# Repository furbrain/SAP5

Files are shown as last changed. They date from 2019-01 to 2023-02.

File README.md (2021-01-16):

# Shetland Attack Pony v5

The Shetland Attack Pony (SAP) now has an integrated laser range finder, and comes with a OLED display, optional bluetooth capability and a wide variety of beeping noises.

[Demo video on YouTube](http://www.youtube.com/watch?v=q_M8_QxNhjs)

## Get Started

**To turn on:**<br>
Press the button

**To turn off:**<br>
Press the button twice in quick succession

**Take a measurement**<br>
Press and hold the button

**To access the menu from the ready to measure screen**<br>
Shake the device

**Navigating menus:**<br>
Tilt the device briefly towards you - this will move on to the 
next menu item. Clicking the button will select that menu item

__DO NOT LOOK DIRECTLY INTO THE LASER BEAM:__ this can cause permanent
eye damage, although a brief exposure of less than a second is
unlikely to cause harm.

## Introduction

The SAP has three main operating modes: 

* [Ready to Measure](#Ready to Measure)
* [Data](#Data)
* [Menu](#Menu)

In many of these modes you will have top and bottom information rows.
Top left shows the time, and top right shows current battery. If you have a bluetooth module installed, you will see a bluetooth symbol, which will indicate whether the device is connected via bluetooth or not. 
The bottom row shows the current measurement style and units

## Ready to Measure

This is the first mode you will meet on starting the SAP. You will see a laser symbol, indicating the SAP is ready to take a reading. When taking a measurement, make sure the SAP is not near any sources of magnetic interference -  headlights, watches, metal anchors.

Press and hold the button to take a reading, keeping the laser dot lined up on your target. The SAP will make a single beep if the reading was successful, and will enter the [Data mode](#Data).

If the reading was unsuccessful you will hear an error noise and the display will briefly display the cause of the error, then return to Ready to Measure.

To directly access [Menu mode](#Menu), just shake the device.

## Data

This mode shows the data from the most recent measurement. If you have set the [display style](#Display style) to Compact then everything will be visible on a single screen. If not, you will need to scroll between the various readings. The default is to display compass reading in degreees, followed by clinometer reading, then distance in metres and finally extension (horizontal distance). You can choose different units of length and angle in [Settings -> Units](#Units), and you can also choose to just view offset in terms of Easting, Northing and Vertical in [Settings -> Style](#Style).
If you press the button on any of the data screens you will return to [Ready to Measure](#Ready to Measure).

There are a few additional options:

### Store
This allows you to store the data to the memory of the SAP and later retrieve it as a survex file using PonyTrainer. If you select this item, it will default to choosing the next leg (e.g) 1 -> 2 or 2->1. You can also select a splay leg with 1-> - or 2 -> -. If neither of these are suitable you can choose custom and specify which two stations this leg connects.

### Discard
Discards the data and return to [Ready to Measure](#Ready to Measure).

### Main Menu
Go to the [Menu](#Menu).

## Menu
### Settings

#### Units (default: metric)
Choose between *metric* (metres) and *imperial* (decimal feet).

#### Style
##### Polar (default)
Directional readings are shown in degrees.

##### Grad
Directional readings are shown in grads. There are 400 grads in a circle.

##### Cartesian
Instead of compass and clino readings, the northing, easting, and vertical distances are
shown. This can aid sketching when used with graph paper. It is also the format
that data is stored internally.

#### Display
##### Compact
When you have taken a reading, show all the data on a single screen
##### Large
When you have taken a readingm, show each data item on it's own screen.

#### Timeout (default 30s)
Select the length of time after which the device turns itself off without any input.

#### Set Date
Sets the current date. For each digit in the date, flip the device away or towards
you to set the correct date. Move on to the next digit by pressing the button.

#### Set Time
Sets the current time. For each digit in the time, flip the device away or towards you to set the correct date. Move on to the next digit by pressing the button.

### Calibrate
This option allows you to calibrate the various sensors within the device. With normal operation, you should only need to use the Calibrate Sensors item - you should do this every few months, or whenever you change general location so that the strength and dip of the magnetic field has changed

#### Sensors
At each stage the screen will give instructions.

1. Place the device flat against an __inclined__ surface and wait for the beep. 
After each beep rotate through 90 degrees - it will take four readings in total.
The positions do not have to be exact, but the device must be still for the half-second before each beep.

2. Place the device flat on a level(ish) surface. After the first beep turn it so the laser is pointing straight up.
After second beep place it with the display facing down. After the third beep place it so the laser is pointing downwards
The positions do not have to be exact, but the device must be still for the half-second before each beep.

3. Hold the laser against a solid point with the laser on a fixed point at least 2 metres away. After each beep
rotate by about 45 degrees, while keeping the laser pointing at the same place. There will be eight
readings in total. It is important that you keep the laser pointing at the same point for each reading.

4. Repeat step 3 using different points, ideally about 90 degrees from the previous set.

The screen will then display some accuracy statistics - ideally the final number should be 1.00 or less.
If the accuracy is good enough, then the calibration will be saved to the devices memory.

#### Laser

This allows you to calibrate the distance returned by the laser. You should only need to do
this if you add anything to the rear of the device or if you want to measure from the front
of the device.

1. Before selecting this option measure a distance of exactly 1m to a flat surface.
2. After selecting this option, place the device so the point you want to measure from is exactly
1m from the flat surface.
3. The device will make 10 beeps and display the new offset for the laser and the error number - this should
be 0.002 or less.

#### Axes

This allows the device to work out which sensors are pointing in which direction. You should not
need to do this unless you have an experimental device.

### Measure
Return to [Ready to Measure](#Ready to Measure)

### Visualise
If you have been storing your recorded legs, this allows you to see what you have recorded so far.
You will see all the legs recorded in the curent survey, move the device to get a different perspective.
Hold the device horizontal and you will see it in plan view. Hold it vertically and you will get an elevation.

This feature is still in development.

### Info
This menu item shows several screens with basic information. It can allow some troubleshooting. Several of 
these refer to the various axes of the device. The y-axis is in the direction of the laser beam. The z-axis goes
up through the top of the device, and the x-axis is at right-angles to both of these.

#### Raw
Show the raw sensor readings. Magnetic readings are in μT, gravitational readings are in g (1g = 9.81ms<sup>-2</sup>).

#### Calibrated
Show the calibrated readings, the top reading is the total field strength (in μT for magnetism, g for gravity).

#### Bearings
Show the current compass and clin readings for the device. Also displays the device name

There are also screens that show the exact battery voltage and firmware/hardware versions

### Off
Turns the device off

## Battery Life
The main draw on the battery is the laser pointer. From a full charge
the device will remain on continuously for about 2½ hours, assuming 15 seconds to read out the compass and clino, 3s
of laser usage to identify the target station and 3s of reading. You should get approx 300 sets of readings,
but your actual results will vary depending on how long you keep the laser on for and
the ambient temperature.

When the battery is getting low you will first get a warning when the device turns on. When the battery is
critically low, the device will not turn on and just make an "error" noise.

## Known Issues

* Visualisation mode is not thoroughly tested.

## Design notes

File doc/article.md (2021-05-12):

Non-linear calibration of a digital compass and accelerometer

#Introduction

The Shetland Attack Pony (SAP) is a cave surveying tool, which has undergone several iterations in its lifetime **FOOTNOTE**. The original version was the first electronic compass/clinometer developed for caving  In its current form it consists of a 32bit CPU (PIC32MM0256GPM028 **FOOTNOTE**), a lithium-ion battery, an OLED display, a laser range finder, an accelerometer (LSM6DS3 by ST **FOOTNOTE**) and a magnetometer (BM1422AGMV by Rohm **FOOTNOTE**). This is an open source project - all the code and hardware designs can be found on Github.

#Principle of Operation

##Laser rangefinder
The laser rangefinder uses a simple time-of-flight algorithm - it sends out pulses of laser light and records the time taken for those pulses to be received back. These are typically accurate to +/- 1mm,

##Magnetometer
The BM1422AGMV uses 3 orthogonal magneto impedance sensors. These consist of a thin film of soft ferromagnetic materials with the special property that their impedance to high frequency alternating current is highly sensitive to any external magnetic fields. The associated IC therefore generates a high frequency alternating current and measures the impedance to determine the magnetic field. This specific sensor is accurate to +/-0.042 uT (Earth's horizontal magnetic field component is typically up to 30 uT, depending on location)

##Accelerometer
The LSM6DS3 use a micro-electro-mechanical system (MEMS) to measure acceleration. This consists of a small mass of silicon on a cantilever between two plates. Under acceleration, the mass moves towards one of the plates, altering the capacitance between the mass and the plate. The LSM6DS3 consists of 3 of these assemblies in an orthogonal pattern. It is accurate to 90 ug (where one g is 9.81 ms^-2)

##Priniciple of determining orientation

###Coordinate system
We shall imagine the SAP initially to be lying flat on a plane with the display upwards. The y coordinate extends in the positive direction parallel to the laser. The z-coordinate extends in a positive direction up through the display. The x-coordinate extends in a positive direction to the left when looking down at the display with the laser pointing away from you 

###Determining orientation
We can use the Magnetometer to determine a vector for gravity g and magnetism m, we can therefore calculate vectors for East and North using the cross-product. 

E = G^ X M^
N = E^ X G^ 

O = (E^ N^ G^)

The matrix O then forms an orthogonal basis and we can use this to translate the y-vector (i.e. the direction of the laser beam) (0,1,0) into real world coordinates y'

y' = yO^T
azimuth = atan2(Y'_1, Y'_0)
inclination = atan2(|(y'_0,y'_1)|, y'_2)

#Traditional calibration

The above calculations of course assume that we have perfect sensors, each exactly aligned, and that there is no magnetic interference from any other components. Unfortunately, none of these assumptions are true. We can divide the potential sources of error into errors intrinsic to the sensors and extrinsic errors

##Intrinsic Errors
Each sensor has an offset β_sensor and a scale factor A_sensor, and also a degree of non-linearity. Non-linearity is the degree to which the sensor reading departs from the straight line, we shall denote it here as psi(x). 

x_sensor = A_sensor x_raw + β_sensor + psi(x_raw)

##Extrinsic Errors
The incident magnetic field on the sensor can be affected by both hard iron β_sensor (which is a simple offset) and soft iron effects A_soft iron(which can be a shear and scale error) within the device.Each sensor can also be rotated with respect both to the ideal orthogonal position, so we also have a 3x3 rotation matrix R for each set of sensors

x = R . A_soft_iron (x_sensor + β_hard_iron)

For the time being, we will ignore the non-linearity term, and we can simplify all this to 

x = A(x_raw + β) 

where A is a 3x3 matrix and β is a 3-vector

##Basic calibration process
We can make a first estimation at A and β by noting that both the gravitational and magnetic fields in any single location should be constant (at least over the time taken to calibrate the device). We take a series of 24 readings, of which eight are distributed in multiple directions and orientations. The other 16 are two sets of eight readings all taken from the same origin to two destination points, with the device held in varying degrees of roll along the y axis. This gives us a cloud of points which are distributed on the surface of an ellipsoid. We can use the process described 

#Issues with non-linearity

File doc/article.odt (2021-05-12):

Non-linear calibration of a digital compass and accelerometer

# Introduction

The Shetland Attack Pony (SAP) is a cave surveying tool, which has undergone several iterations in its lifetime[1][2].The original version was the first electronic compass/clinometer developed for caving In its current form it consists of a 32bit CPU (PIC32MM0256GPM028 by Microchip[3]), a lithium-ion battery, an OLED display, a laser range finder, an accelerometer (LSM6DS3 by ST[4]) and a magnetometer (BM1422AGMV by Rohm[5]). This is an open source project - all the code and hardware designs can be found on Github[6].

# Principle of Operation

## Laser rangefinder

The laser rangefinder uses a simple time-of-flight algorithm - it sends out pulses of laser light and records the time taken for those pulses to be received back. These are typically accurate to +/- 1mm.

## Magnetometer

The BM1422AGMV uses 3 orthogonal magneto-impedance sensors. These consist of a thin film of soft ferromagnetic materials with the special property that their impedance to high frequency alternating current is highly sensitive to any external magnetic fields. The associated IC therefore generates a high frequency alternating current and measures the impedance to determine the magnetic field. This specific sensor is accurate to +/-0.042 μT (Earth's horizontal magnetic field component is typically up to 30 μT, depending on location)

## Accelerometer

The LSM6DS3 use a micro-electro-mechanical system (MEMS) to measure acceleration. This consists of a small mass of silicon on a cantilever between two plates. Under acceleration, the mass moves towards one of the plates, altering the capacitance between the mass and the plate. The LSM6DS3 consists of 3 of these assemblies in an orthogonal pattern. It is accurate to +/-90 μg (where one g is 9.81 ms⁻²)

## Determining orientation

We shall imagine the SAP initially to be lying flat on a plane with the display upwards. The y-coordinate extends in the positive direction parallel to the laser. The z-coordinate extends in a positive direction up through the display. The x-coordinate extends in a positive direction to the left when looking down at the display with the laser pointing away from you

We can use the magnetometer and accelerometer to determine a vector for gravity g and magnetic field m. From these we can calculate vectors for East and North using the cross-product.

bold e = bold hat g times bold hat m newline
bold n = bold hat e times bold hat g newline
O = ( bold hat e bold hat n bold hat g )

The orientation matrix O then forms an orthogonal basis and we can use this to translate the y-vector (i.e. the direction of the laser beam (0,1,0) ) into real world coordinates y

bold y = O left (stack { 0 # 1 # 0 } right ) newline
azimuth = func atan2(y_1, y_0) newline
inclination = func atan2( sqrt{y_1^2 + y_0^2}, y_2 )

# Traditional calibration

The above calculations of course assume that we have perfect sensors, each exactly aligned, and that there is no magnetic interference from any other components. Unfortunately, none of these assumptions are true. We can divide the potential sources of error into errors intrinsic to the sensors and extrinsic errors

## Intrinsic Errors

Each sensor has an offset βsensor and a scale factor Asensor, and also a degree of non-linearity. Non-linearity is the degree to which the sensor reading departs from the straight line, we shall denote it here as an arbitrary, unknown function ψ(x), where x is the sensor reading.

bold x_sensor = A_sensor bold x_raw + bold β_sensor + %psi(bold x_raw)

## Extrinsic Errors

The incident magnetic field on the sensor can be affected by both hard iron βsensor (which is a simple offset) and soft iron effects Asoft iron(which can be a shear and scale transformation) within the device. Each sensor can also be rotated with respect both to the ideal orthogonal position, and also with respect to the device, so we also have a 3x3 rotation matrix R for each set of sensors.

bold x = R A_{soft iron} (bold x_sensor + bold β_{hard iron})

For the time being, we will ignore the non-linearity term, and we can simplify all this to

bold x = A(bold x_raw + bold β)

where A is a 3x3 matrix and β is a 3-vector

## Basic calibration process

We can make a first estimation at A and β by noting that both the gravitational and magnetic fields in any single location should be constant (at least over the time taken to calibrate the device). We take a series of 24 readings, of which eight are distributed in multiple directions and orientations. The other 16 are two sets of eight readings all taken from the same origin to two destination points, with the device held in varying degrees of roll along the y axis. This gives us a cloud of points which are distributed on the surface of an ellipsoid. We can use the process described in Vitali[7] to calculate the closest values for A and β. This method is rather involved but essentially calculates the matrix and offset required that would translate all of the stored data points onto the surface of a unit sphere located at the origin, and minimises the average distance of any translated point from that surface. The error of this process can be estimated as below where N is the number of readings.

h_magnitude = sqrt{ sum from{i=0} to{N} {(abs {bold x_i} - 1)^2 over N} }

## Correcting for rotation

Once this process is complete, we still have the possibility of error due to misalignment between our sensors and the laser pointer. Essentially we need to find the vector v in sensor coordinates that corresponds to the direction of the laser pointer. Consider the two sets of eight readings taken during calibration – for each set the angle between the laser pointer and the magnetic/gravitational fields will be constant. They will therefore be located on a plane, which is normal to v.

a X + b Y + c Z = 1 newline

D left ( stack{ a # b # c} right )= left ( stack{1 # dotsvert # 1} right ) newline

bold v = left ( stack{ a # b # c} right )

We can use the equation for a plane to construct an equation where D is a 3x8 matrix consisting of the sensor readings from the particular set of readings. Solving this with a least squares technique gives us a, b, and c which can be used to construct v. Once v is determined, it is trivial to construct a rotation matrix that can be applied to A to give us sensor readings in device coordinates.

We can also use these sets of readings to develop another measure of accuracy – essentially how similar the laser pointer vectors are in real world coordinates:

h_orientation = sum from {i=0} to N {abs{bold y_i - bold bar y} over N}

yi is the ith reading of a set in real world coordinates and bold bar y is the average of all of those readings.

# Issues with non-linearity

The previous calibration process worked on the principle that the output of the sensors varies linearly with the incident magnetic or gravitational field. This is not always true, and the output of the BM1422AGMV in particular can have non-linearity of up to 2.8%. Figure 1 shows the consequences of a 0.01 error (where 1 is the maximum reading when the sensor is aligned with the magnetic field). As we can see the error in magnitude is greatest at larger sensor values, whereas the error in the azimuth (which is what we are interested in as cave surveyors) is greatest around the zero point. As the traditional calibration algorithm seeks to minimize errors in magnitude

To progress we need to find a way to determine the unknown function ψ(x). One common way to approximate an unknown function is to use polynomial fitting e.g:

%psi( bold x ) = sum from i=0 to P p_i x^i

Where pi is the ith of P polynomial coefficients. Usually somewhere between 2 and 10 coefficients are sufficient to approximate any arbitrary continuous function. Unfortunately polynomial equations behave badly outside of the fitted range, which may cause problems if the device is moved to other locations with a stronger magnetic field. Instead, we can use a radial basis function as below.

%psi(bold x) = sum from {i=0} to P %phi(p_i, a_i, bold x) newline

%phi(p, a, bold x) = p func e^{-((bold x' - a) P/2 )^{2}} newline

a_i = left lbrace matrix { 0 # func if P=1 ## {2i} over {P-1} - 1# func if P > 1} right rbrace

This creates a set of P gaussian curves that can be added together to form an arbitrary function, but which rapidly tail off outside the interval (-1,1). x’ is the raw sensor value, scaled and offset to fit in the range (-1,1) - scale and offset factors can easily be calculated from A and β. Figure 2 shows a arbitrary function constructed from these radial basis functions. As you can see these functions tend towards zero outside of their fitted range.

We can now use a minimisation algorithm to find the ideal values for p that minimises h (note that we still need to include hmagnitude as otherwise the minimisation algorithm can find extreme values)

bold p = func argmin_{bold p} h newline
h = h_orientation + h_magnitude

In principle we could then repeat the ellipsoid fitting algorithm; however in practice this does not produce any substantial gains in accuracy.

# Overfitting

One risk of approximating arbitrary functions is that of overfitting – where the generated function is determined more by noise in the data than by the underlying structure. As we increase the number of parameters for We can assess for this using a “leave-one-out” technique – essentially running the whole calibration process excluding the first data point and seeing how well that data point is placed using the calibrated constants, and then repeating this over all data points. This can be done using different number of parameters, and we can generally find a “sweet spot” where we have enough parameters to model the non-linearity, but not enough to fall prone to overfitting. Figure 3 shows several data points, which shows some data points from the cosine function with some added noise, with several polynomial approximations shown. The red line is underfitted with only 3 parameters, and misses the peak of the curve and also the tails on either side. The blue line is overfitted, and you can see it responding to noise in the data points, and also rapidly becomes unstable outside of the fitted range. The green line is “just right”and models the general shape of the data without getting too distorted by noise.

# Results

Nine SAPs were constructed and calibration data was obtained as described in the basic calibration process. The calibration algorithm described was then applied with between 0 and 9 parameters for the non-linear correction (P). P=0 is equivalent to just using the “traditional” calibration method. The results are shown in Figure 4, and show that the majority of the benefit is achieved with 3 to 5 parameters, and then only gradual improvement thereafter with more parameters.

The same procedure was also performed using a leave-one-out strategy to determine if there is any overfitting. The results are shown in figure 5 – they demonstrate good improvement in accuracy with up to 5 non-linear parameters. Using more than 5 parameters impaired performance due to overfitting, with severe problems when 8 or more parameters are used.

# Conclusions

This paper has demonstrated that non-linear effects in magnetometers can cause significant errors for electronic compasses that cannot be compensated with traditional calibration mechanisms. Where devices have a pointer, these errors can be minimised with the use of the technique demonstrated.

However, this technique can only correct for non-linearity in the x and z axes, as the y-axis sensor reading will not change substantially during rotation around the y-axis. It should be possible to use the flat bottom of a survey device as a way to rotate the device accurately around the z-axis, and this may provide a way to obtain a y-axis non-linear calibration– this is yet to be explored.

# References

[1] P. Underwood, ‘A Combined Electronic Compass and Clinometer’, Cave Radio Electron. Group J., no. 66, pp. 12–14, Mar. 2007.

[2] P. Underwood, ‘Calibrating the Electronic Compass/Clinometer’, Cave Radio Electron. Group J., no. 69, pp. 10–13, Dec. 2007.

[3] Microchip Technology Inc., ‘PIC32MM0256GPM028 - 32-bit PIC Microcontrollers’. https://www.microchip.com/wwwproducts/en/PIC32MM0256GPM028 (accessed May 11, 2021).

[4] STMicroelectornics, ‘LSM6DS3 - iNEMO 6DoF inertial measurement unit (IMU), for consumer electronics - STMicroelectronics’. https://www.st.com/en/mems-and-sensors/lsm6ds3.html (accessed May 11, 2021).

[5] Rohm, ‘BM1422AGMV - 3-Axis Digital Magnetometer IC | ROHM Semiconductor - ROHM Co., Ltd.’ https://www.rohm.com/products/sensors-mems/geomagnetic-sensor-ics/bm1422agmv-product (accessed May 11, 2021).

[6] P. Underwood, SAP5 Github Repository. 2021. Accessed: May 11, 2021. [Online]. Available: https://github.com/furbrain/SAP5

[7] A. Vitali, ‘Ellipsoid or sphere fitting for sensor calibration’. STMicroelectronics. Accessed: Apr. 17, 2021. [Online]. Available: https://www.st.com/resource/en/design_tip/dm00286302-ellipsoid-or-sphere-fitting-for-sensor-calibration-stmicroelectronics.pdf

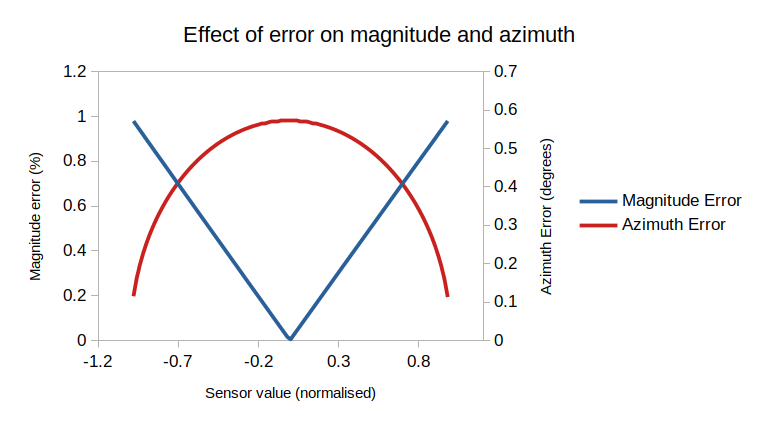
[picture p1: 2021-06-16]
doc/images/mag_azi_error.png

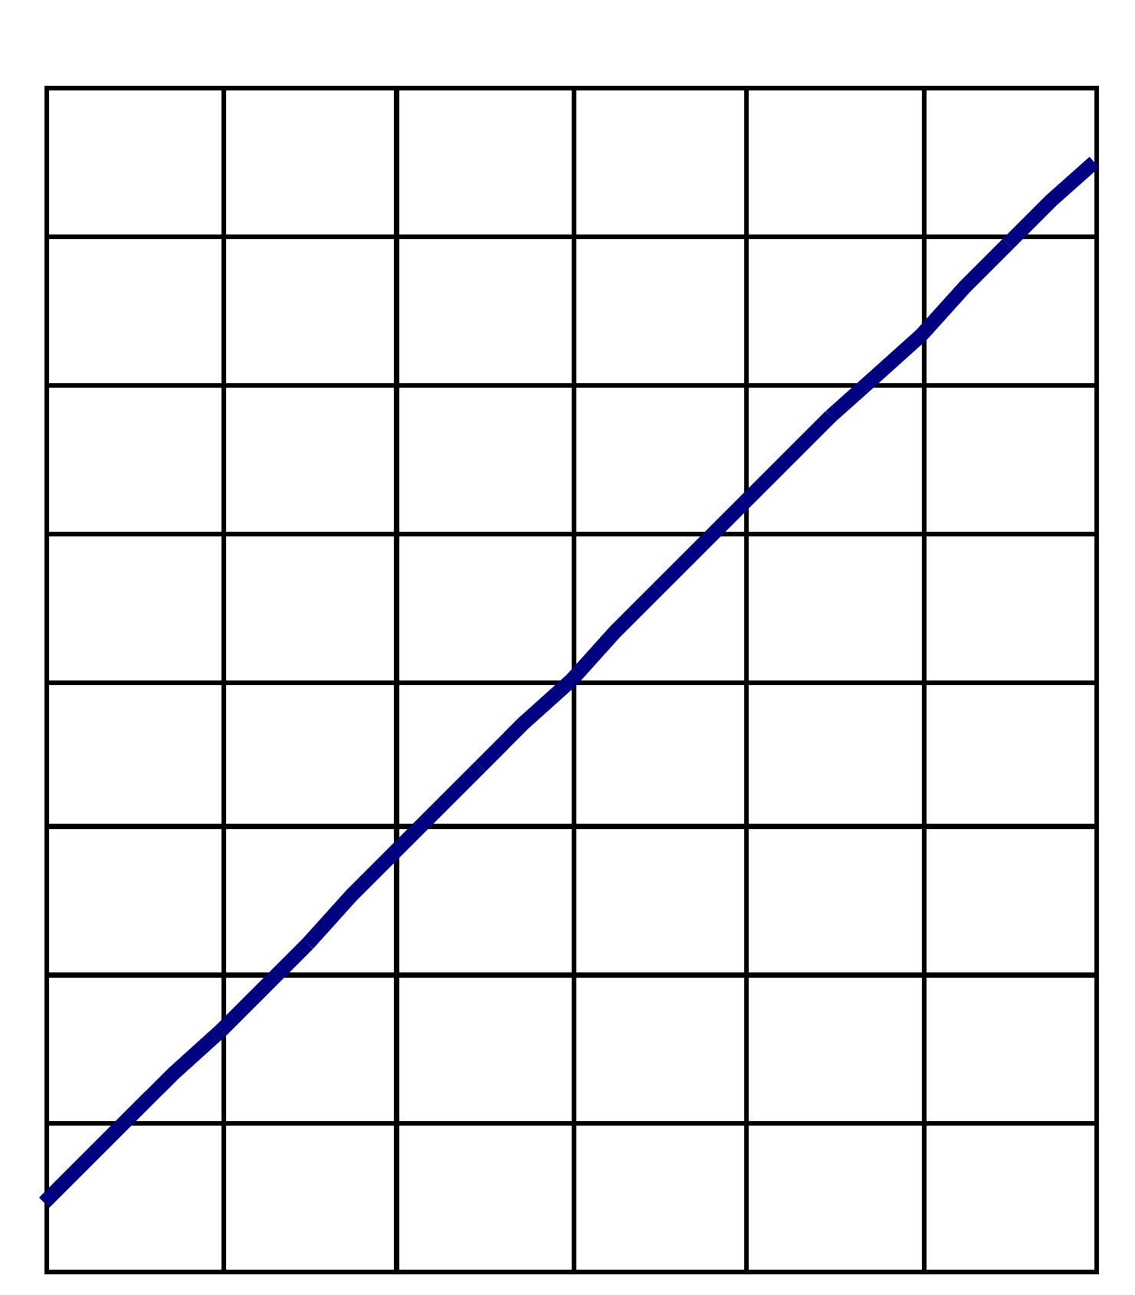
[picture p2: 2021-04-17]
chips/BM1422/graph.png

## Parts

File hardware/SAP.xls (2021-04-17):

Designator | MPN/Seeed SKU | Qty | Link
B1 | 320110026 | 1 | https://statics3.seeedstudio.com/images/opl/datasheet/3410050P1.pdf
C1, C2, C4, C21, C23, C26, C27 | 302010024 | 7 | https://statics3.seeedstudio.com/images/opl/datasheet/302010024.pdf
C3, C22 | 302010103 | 2 | https://statics3.seeedstudio.com/images/opl/datasheet/302010103.pdf
C11, C12, C14, C15, C19, C20 | 302010146 | 6 | https://statics3.seeedstudio.com/images/opl/datasheet/302010146.pdf
C24, C25 | 302010003 | 2
J4 | UJ2-MIBH-4-SMT-TR-67 | 1 | https://www.digikey.com.cn/product-detail/zh/cui-inc-/UJ2-MIBH-4-SMT-TR-67/102-4970-1-ND/9564435
R1, R10, R12 | 301010004 | 3 | https://statics3.seeedstudio.com/images/opl/datasheet/301010004.pdf
R2, R11 | 301010006 | 2 | https://statics3.seeedstudio.com/images/opl/datasheet/301010006.pdf
R3, R4, R5 | 301010009 | 3 | https://statics3.seeedstudio.com/images/opl/datasheet/301010009.pdf
R7 | 301010466 | 1 | https://statics3.seeedstudio.com/images/opl/datasheet/301010466.pdf
R8, R9 | 301010039 | 2 | https://statics3.seeedstudio.com/images/opl/datasheet/301010039.pdf
U1. | PIC32MM0256GPM028-I/SS | 1 | https://www.digikey.com.cn/product-detail/zh/microchip-technology/PIC32MM0256GPM028-I-SS/PIC32MM0256GPM028-I-SS-ND/7354783
U6. | XC6215B302MR-G | 1 | http://www.mouser.cn/ProductDetail/Torex-Semiconductor/XC6215B302MR-G
U8. | MC78LC30NTRG | 1 | https://www.digikey.com.cn/product-detail/zh/on-semiconductor/MC78LC30NTRG/MC78LC30NTRGOSCT-ND/1967131
U9. | MAX1555EZK+T | 1 | https://www.digikey.com.cn/product-detail/zh/maxim-integrated/MAX1555EZK-T/MAX1555EZK-TCT-ND/2699449
U10. | OV-7604-C7-32.768kHz-20PPM-TA-QC | 1 | https://www.mouser.cn/ProductDetail/Micro-Crystal/OV-7604-C7-32768kHz-20PPM-TA-QC
U11 | BM1422AGMV-ZE2 | 1
U12 | LSM6DS3TR | 1

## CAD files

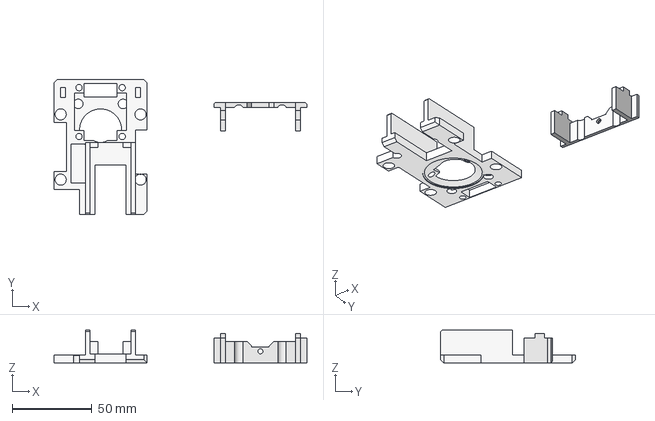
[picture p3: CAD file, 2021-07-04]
enclosures/frame.FCStd
158.5 x 84.4 x 20.5 mm
Base
Cage

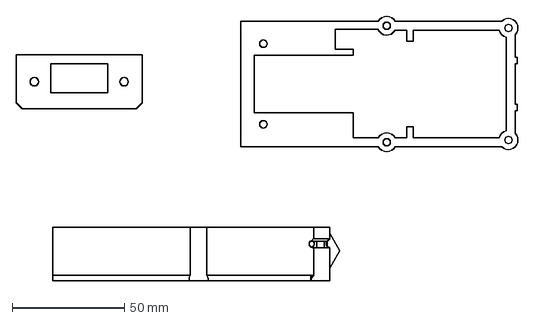
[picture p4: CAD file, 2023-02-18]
enclosures/v2/gaskets.dxf
223.9 x 118.0 mm

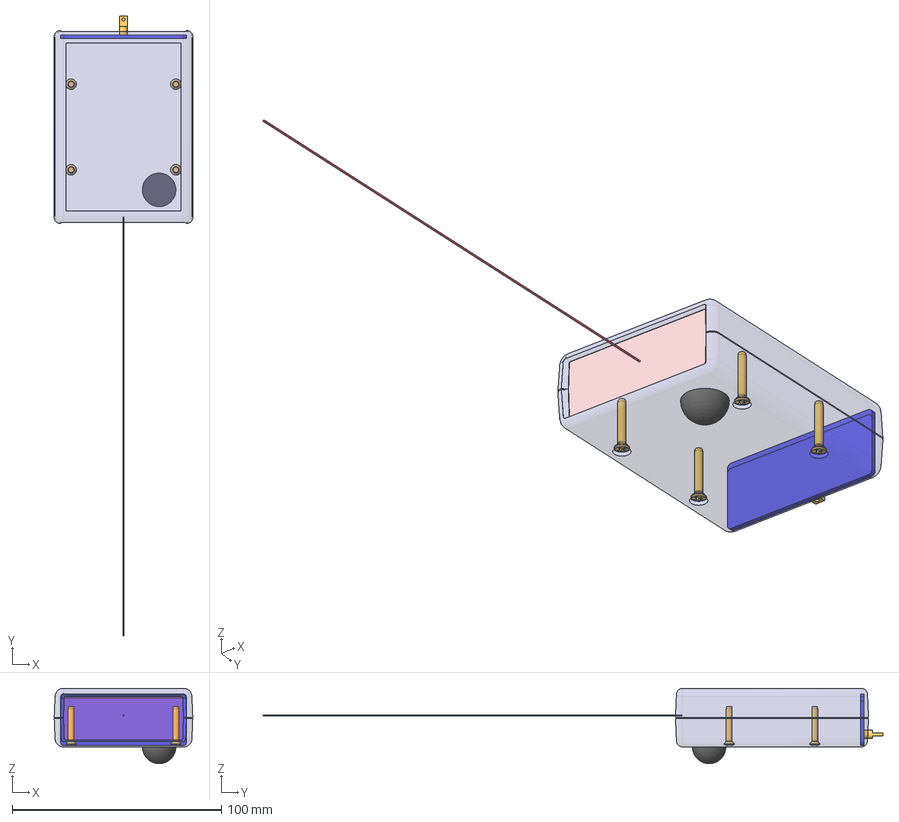
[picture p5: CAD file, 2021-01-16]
enclosures/model.FCStd
66.2 x 296.0 x 36.0 mm
_593L
_593L001
_593L002
_593L003
_593L007
_593L008
_593L009
_593L010

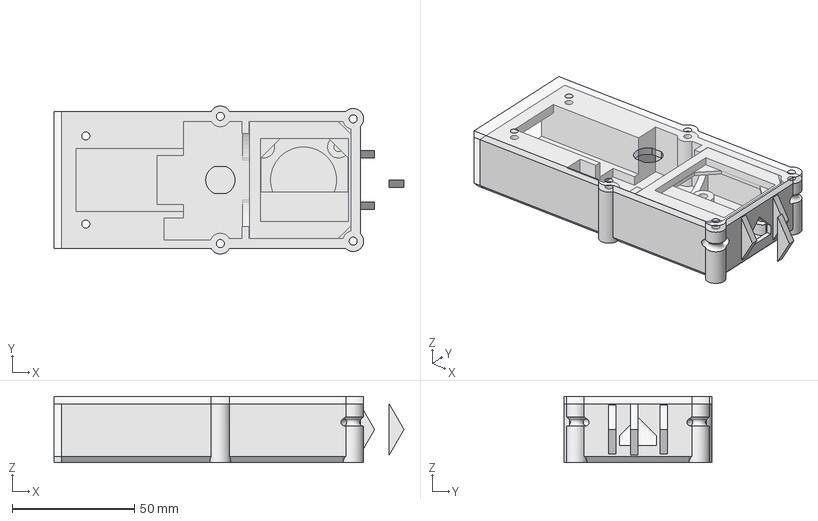
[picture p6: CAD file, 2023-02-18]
enclosures/v2/model.FCStd
143.1 x 60.5 x 27.0 mm
Main Body
Front Plate
Top Plate
LCD Holder
Noddle

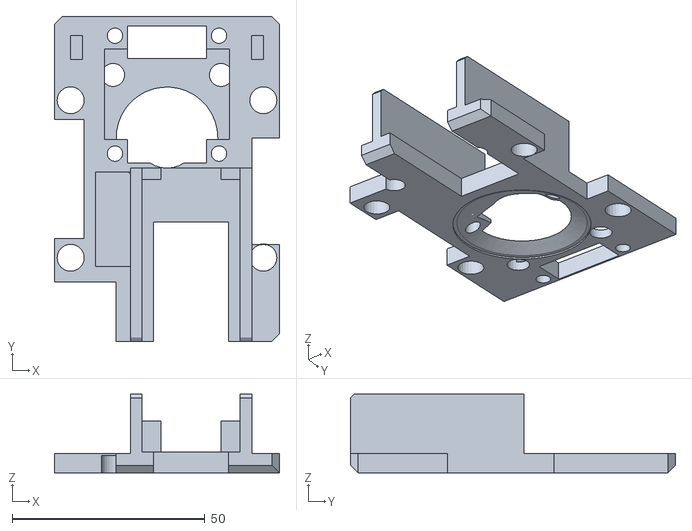
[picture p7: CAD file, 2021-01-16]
enclosures/base.stl
58.4 x 84.4 x 20.5

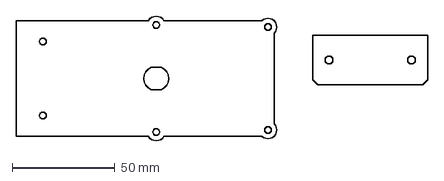
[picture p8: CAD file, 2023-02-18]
enclosures/v2/acrylic.dxf
199.9 x 60.5 mm

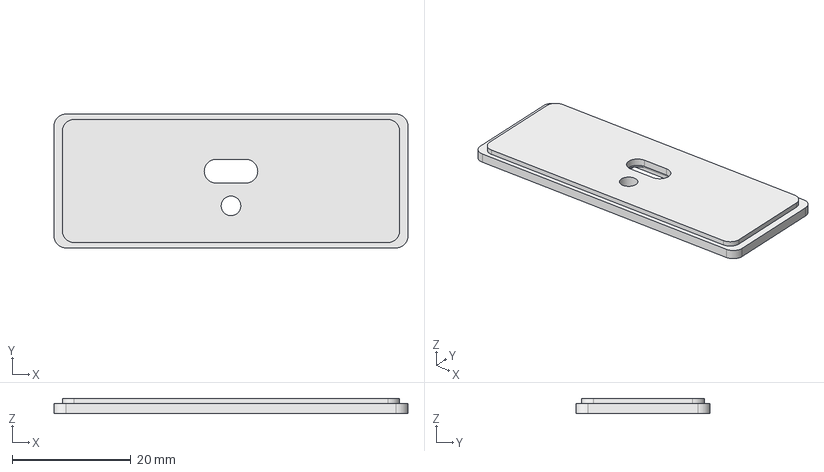
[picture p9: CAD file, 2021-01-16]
enclosures/end_panel2.FCStd
59.5 x 22.5 x 2.60 mm

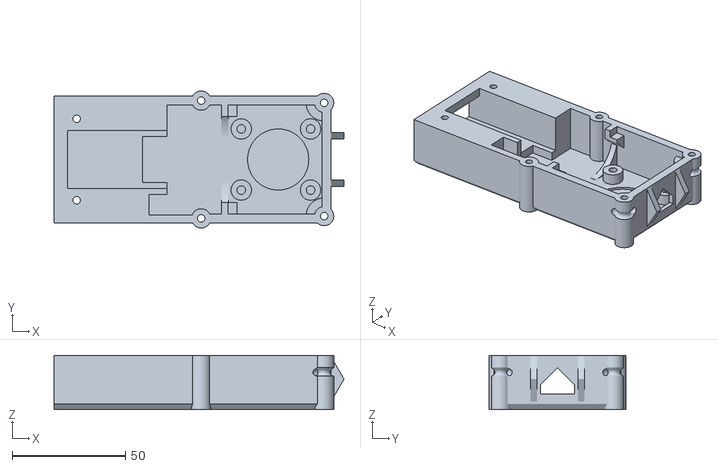
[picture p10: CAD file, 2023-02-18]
enclosures/v2/model-Body.stl
128.1 x 60.5 x 24.0

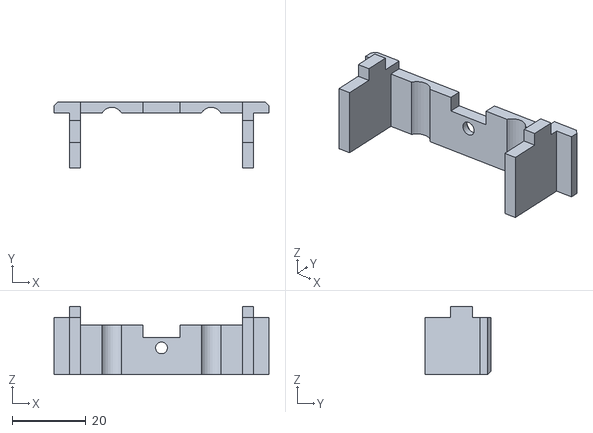
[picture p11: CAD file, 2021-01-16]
enclosures/cage.stl
58.4 x 18.0 x 18.5

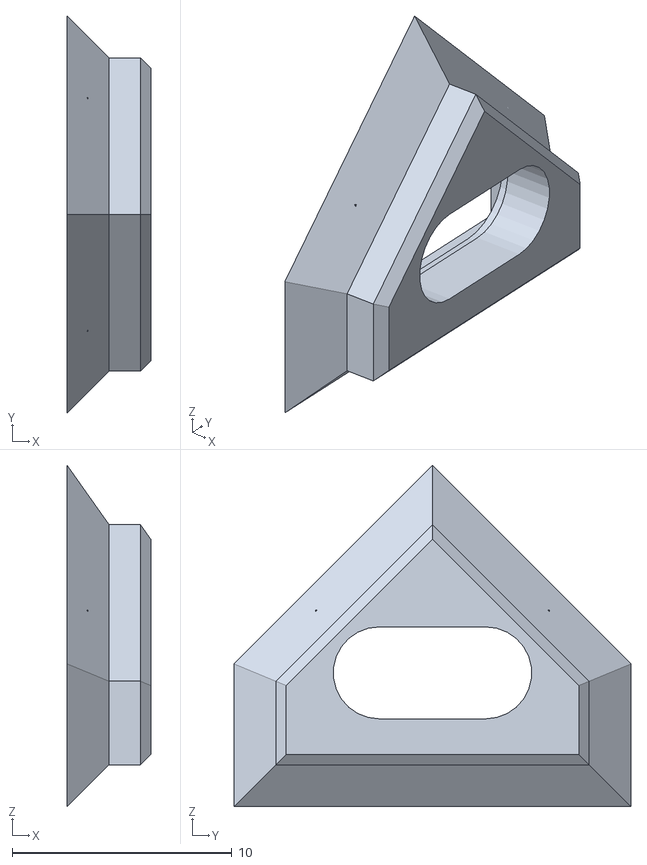
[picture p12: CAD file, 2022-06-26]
enclosures/v2/model_end_widget.stl
3.80 x 18.0 x 15.5

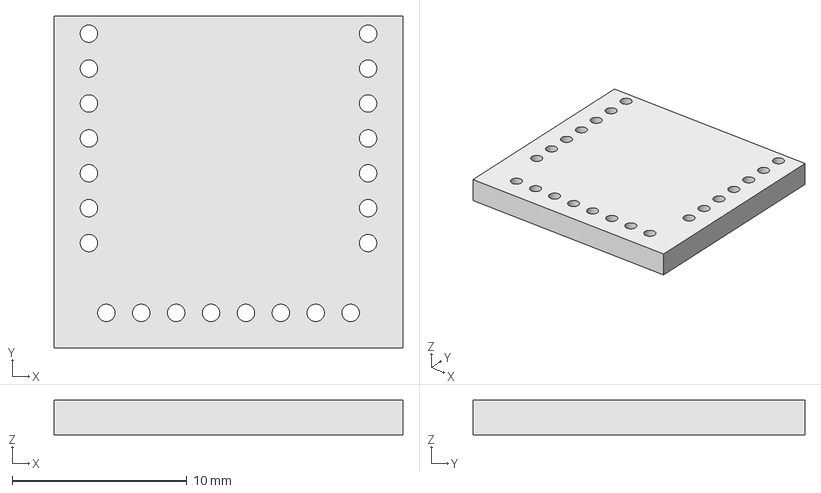
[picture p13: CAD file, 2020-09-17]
enclosures/ble_mount_jig.FCStd
20.0 x 19.0 x 2.00 mm

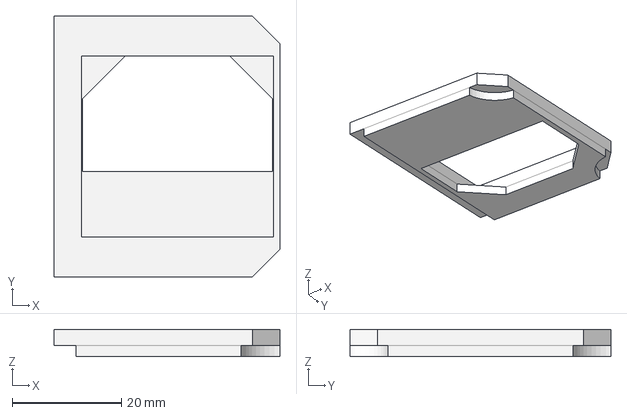
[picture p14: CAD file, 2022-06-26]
enclosures/v2/model-LCD Holder.step
41.3 x 47.8 x 5.00 mm

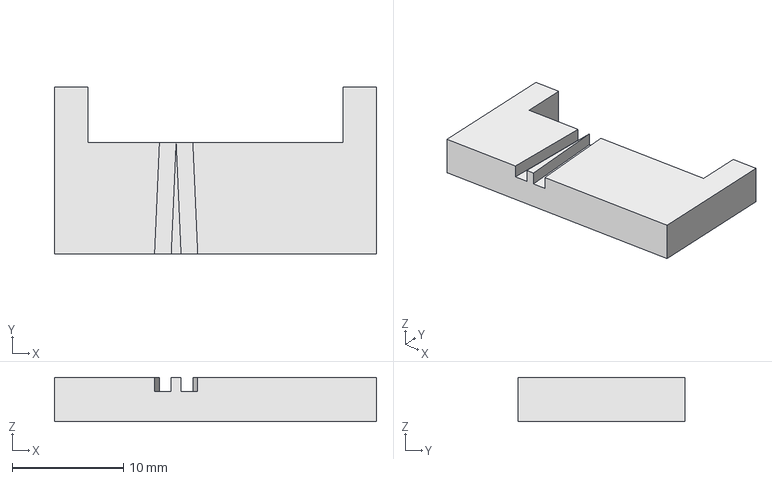
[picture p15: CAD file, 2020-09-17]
enclosures/laser_jig.FCStd
29.0 x 15.0 x 4.00 mm

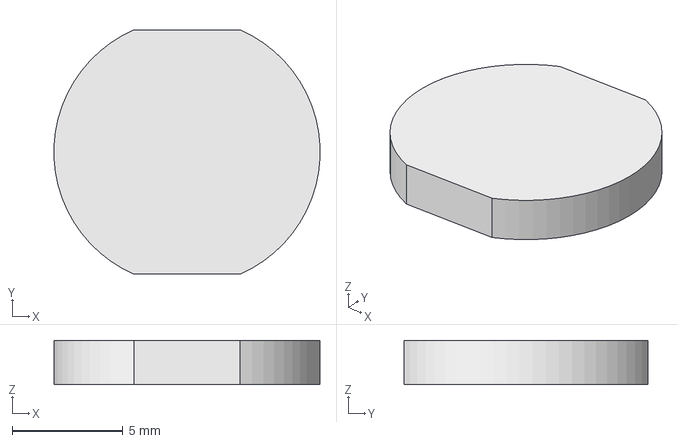
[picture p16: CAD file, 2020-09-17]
enclosures/button_hole.fcstd
12.0 x 11.0 x 2.00 mm

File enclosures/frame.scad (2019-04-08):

module rod(a, b, width) {
    delta = b-a;
    length =norm(delta);
    translate(a) rotate([0,0,atan2(delta[1],delta[0])])
        translate([0,-width/2,0]) cube([length,width,width]);
}

$fn=30;

mount_holes = [[-14, 27, 0],
               [14, 27, 0]];

support_struts = [[-25, -20.43, 0],
                  [25, -20.43, 0],
                  [-25, 20.43, 0],
                  [25, 20.43, 0]];

screw_dents = [[-14.5,-37.6],
               [14.5,-37.6],
               [-14.5,-6.2],
               [14.5,-6.2]];

corners = [[-25,-38],
           [25,-38]];

module beta(width, height) {
    difference() {
        union() {
            for(i=[0,1]) {
                rod(support_struts[i], screw_dents[i+2],width);
                rod(support_struts[i], corners[i],width);
                rod(corners[i], screw_dents[i], width);
                rod(screw_dents[i+2],mount_holes[i],width);
            }
            rod(support_struts[3], mount_holes[1],width);
            rod(support_struts[3], screw_dents[3], width);
            for(i = [0,2]) {
                for(j = [mount_holes, screw_dents]) {
                    rod(j[i],j[i+1],width);
                }
            }
            for(i=mount_holes) {
                translate(i) cylinder(d=5.7+4,h=height);
            }
            for(i=support_struts) {
                translate(i) cylinder(d=6.6+4,h=height);
            }
            for(i=screw_dents) {
                translate(i) cylinder(d=6.2+4,h=6);
            }
            //laser holder
            translate([-22,-2,0]) cube([29,42,height+6]);
            
            //battery holder
            translate([-22,-2,0]) cube([34,22,height+3]);
        }
        for(i=mount_holes) {
            translate(i) cylinder(d=5.7,h=height*3, center=true);
        }
        for(i=support_struts) {
            translate(i) cylinder(d=6.6,h=height*8, center=true);
        }
        for(i=screw_dents) {
            translate([0,0,2]) translate(i) cylinder(d=6.2,h=height+8);
        }

        //battery pack
        translate([-20,0,-0.1]) cube([30,18,8]);
        translate([-22.1,0,-0.1]) cube([2.3,2,8.5]);
        //laser_holder
        translate([-20,0,height+3]) cube([25,45,14]);
        translate([-17,-4,height+3]) cube([16,8,8]);
        //speaker
        translate([0,-10,-0.1]) cylinder(d=36,h=1);
    }
}
       
intersection() {
    cube([55,80,100],center=true);
    beta(3,4);
}

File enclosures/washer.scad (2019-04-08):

$fn=30;
difference() {
    cylinder(d=6,h=1.5);
    cylinder(d=3.2, h=4, center=true);
}

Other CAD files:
enclosures/end_panel.fcstd
enclosures/end_panel_create.dxf
enclosures/end_panel_jig.fcstd
enclosures/rangefinder.stp
enclosures/ble_mount_jig.stl
enclosures/box.fcstd
enclosures/boxl.fcstd
enclosures/button.fcstd
enclosures/button_hole.dxf
enclosures/end_panel.dxf
enclosures/end_panel2.dxf
enclosures/end_panel2.stl
enclosures/end_panel_jig.dxf
enclosures/frame.stl
enclosures/laser_jig.stl
enclosures/v2/gaskets_old.dxf
enclosures/v2/model-LCD Holder.iges
enclosures/v2/model-LCD Holder.stl
enclosures/washer.stl

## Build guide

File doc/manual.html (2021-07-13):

# Shetland Attack Pony v5

The Shetland Attack Pony (SAP) now has an integrated laser range finder, and comes with a OLED display, optional bluetooth capability and a wide variety of beeping noises.

Demo video on YouTube (http://www.youtube.com/watch?v=q_M8_QxNhjs)

## Get Started

To turn on:
Press the button twice in quick succession

To turn off:
Press the button twice in quick succession

Take a measurement
Press and hold the button

To access the menu from the ready to measure screen
Shake the device

Navigating menus:
Tilt the device briefly towards you - this will move on to the next menu item. Clicking the button will select that menu item

Bluetooth:
The Pin (if you need it) is 000000 (yes, six zeroes)

DO NOT LOOK DIRECTLY INTO THE LASER BEAM: this can cause permanent eye damage, although a brief exposure of less than a second is unlikely to cause harm.

## Introduction

The SAP has three main operating modes:

- Ready to Measure
- Data
- Menu

In many of these modes you will have top and bottom information rows. Top left shows the time, and top right shows current battery. If you have a bluetooth module installed, you will see a bluetooth symbol, which will indicate whether the device is connected via bluetooth or not. The bottom row shows the current measurement style and units

## Ready to Measure

This is the first mode you will meet on starting the SAP. You will see a laser symbol, indicating the SAP is ready to take a reading. When taking a measurement, make sure the SAP is not near any sources of magnetic interference - headlights, watches, metal anchors.

Press and hold the button to take a reading, keeping the laser dot lined up on your target. The SAP will make a single beep if the reading was successful, and will enter the Data mode.

If the reading was unsuccessful you will hear an error noise and the display will briefly display the cause of the error, then return to Ready to Measure.

To directly access Menu mode, just shake the device.

## Data

This mode shows the data from the most recent measurement. If you have set the display style to Compact then everything will be visible on a single screen. If not, you will need to scroll between the various readings. The default is to display compass reading in degreees, followed by clinometer reading, then distance in metres and finally extension (horizontal distance). You can choose different units of length and angle in Settings -> Units, and you can also choose to just view offset in terms of Easting, Northing and Vertical in Settings -> Style. If you press the button on any of the data screens you will return to Ready to Measure.

There are a few additional options:

### Store

This allows you to store the data to the memory of the SAP and later retrieve it as a survex file using PonyTrainer. If you select this item, it will default to choosing the next leg (e.g) 1 -> 2 or 2->1. You can also select a splay leg with 1-> - or 2 -> -. If neither of these are suitable you can choose custom and specify which two stations this leg connects.

### Discard

Discards the data and return to Ready to Measure.

### Main Menu

Go to the Menu.

## Menu

### Settings

#### Units (default: metric)

Choose between metric (metres) and imperial (decimal feet).

#### Style

##### Polar (default)

Directional readings are shown in degrees.

##### Grad

Directional readings are shown in grads. There are 400 grads in a circle.

##### Cartesian

Instead of compass and clino readings, the northing, easting, and vertical distances are shown. This can aid sketching when used with graph paper. It is also the format that data is stored internally.

#### Display

##### Compact

When you have taken a reading, show all the data on a single screen

##### Large

When you have taken a reading, show each data item on it's own screen.

#### Timeout (default 30s)

Select the length of time after which the device turns itself off without any input.

#### Set Date

Sets the current date. For each digit in the date, flip the device away or towards you to set the correct date. Move on to the next digit by pressing the button.

#### Set Time

Sets the current time. For each digit in the time, flip the device away or towards you to set the correct date. Move on to the next digit by pressing the button.

### Calibrate

This option allows you to calibrate the various sensors within the device. With normal operation, you should only need to use the Calibrate Sensors item - you should do this every few months, or whenever you change general location so that the strength and dip of the magnetic field has changed

#### Sensors

At each stage the screen will give instructions.

1. Place the device flat against an inclined surface and wait for the beep. After each beep rotate through 90 degrees - it will take four readings in total. The positions do not have to be exact, but the device must be still for the half-second before each beep.
2. Place the device flat on a level(ish) surface. After the first beep turn it so the laser is pointing straight up. After second beep place it with the display facing down. After the third beep place it so the laser is pointing downwards The positions do not have to be exact, but the device must be still for the half-second before each beep.
3. Hold the laser against a solid point with the laser on a fixed point at least 2 metres away. After each beep rotate by about 45 degrees, while keeping the laser pointing at the same place. There will be eight readings in total. It is important that you keep the laser pointing at the same point for each reading.
4. Repeat step 3 using different points, ideally about 90 degrees from the previous set.

The screen will then display some accuracy statistics - ideally the final number should be 0.40 or less. If the accuracy is good enough, then the calibration will be saved to the devices memory.

#### Laser

This allows you to calibrate the distance returned by the laser. You should only need to do this if you add anything to the rear of the device or if you want to measure from the front of the device.

1. Before selecting this option measure a distance of exactly 1m to a flat surface.
2. After selecting this option, place the device so the point you want to measure from is exactly 1m from the flat surface.
3. The device will make 10 beeps and display the new offset for the laser and the error number - this should be 0.002 or less.

#### Axes

This allows the device to work out which sensors are pointing in which direction. You should not need to do this unless you have an experimental device.

### Measure

Return to Ready to Measure

### Visualise

If you have been storing your recorded legs, this allows you to see what you have recorded so far. You will see all the legs recorded in the current survey, move the device to get a different perspective. Hold the device horizontal and you will see it in plan view. Hold it vertically and you will get an elevation.

This feature is still in development.

### Info

This menu item shows several screens with basic information. It can allow some troubleshooting. Several of these refer to the various axes of the device. The y-axis is in the direction of the laser beam. The z-axis goes up through the top of the device, and the x-axis is at right-angles to both of these.

#### Raw

Show the raw sensor readings. Magnetic readings are in μT, gravitational readings are in g (1g = 9.81ms⁻²).

#### Calibrated

Show the calibrated readings, the top reading is the total field strength (in μT for magnetism, g for gravity).

#### Bearings

Show the current compass and clin readings for the device. Also displays the device name

There are also screens that show the exact battery voltage and firmware/hardware versions

### Off

Turns the device off

## Battery Life

The main draw on the battery is the laser pointer. From a full charge the device will remain on continuously for about 2½ hours, assuming 15 seconds to read out the compass and clino, 3s of laser usage to identify the target station and 3s of reading. You should get approx 300 sets of readings, but your actual results will vary depending on how long you keep the laser on for and the ambient temperature.

When the battery is getting low you will first get a warning when the device turns on. When the battery is critically low, the device will not turn on and just make an "error" noise.

## Known Issues

- Visualisation mode is not thoroughly tested.

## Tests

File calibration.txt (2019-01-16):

Calibration routine:
    For each step record ~200 lots of data points
    
1) Rotate on Z axis, device on flat surface (does not need to be 100% horizontal)
    - gets you range/offset for Mx and My
    - allows for hard/soft iron correction for Mx and My (and scale correction)
    - however offset can be affected by any errors in chip orientation

2) Rotate on Y axis, laser pointing at fixed point, roughly facing east (or west)
    - gets you offset for Mx and Mz
    - gets you offset for Gx and Gz
    - again do hard/soft iron correction for Mx and Mz
    - gets you sensor adjustment for both M and G (in only scope that matters)

3) Rotate on Z axis,device against flat wall
    - gets you range and offset for Gy and Gx

- accelerometer offset should only need calibrating very infrequently

So magnetic calibration:
    Do 1) and 2), record M for 1 and M&G for 2
        a) Do offset calculations for Mx, My, Mz
        aa) correct for chip orientation and re-calculate chip orientations...
        b) Confirm Mx1 and Mx2 offsets are similar - take average as true result
        c) Perform magnetic adjustment for readings from 1, with calibration from a) already applied
        d) Perform 2ary magnetic adjustment for readings from 2) with calibration from c) already applied
        e) Perform adjustment for malalignment of sensors in device for G and M on readings from 2)

Accel calibration:
    Do 2) and 3), record accel readings only
        do offset calculations for Gx Gy Gz only
        Take average of two Gx offsets as true result
        
Magnetometer readings:

Display on:
x, y, z in uT
display on vs off:
[ -3.48148193  12.17581787   8.92743408]
[ 0.28091695  0.30837193  0.31316587]
[ -3.45749756  12.02141846   9.00088623]
[ 0.31096247  0.3239235   0.29510114]
pvalue=array([ 0.56968442,  0.0007218 ,  0.0909947 ]))

[ -3.31059326  11.91498779   8.91843994]
[ 0.307949    0.27281712  0.3325831 ]
[ -3.21990234  11.93372559   8.97765137]
[ 0.31137138  0.28845589  0.29765714]
pvalue=array([ 0.04065736,  0.63917278,  0.18836694]))

[ -3.47698486  11.92697998   8.85398193]
[ 0.28321131  0.27836163  0.32750403]
[ -3.44400635  11.98694092   8.97540283]
[ 0.29132297  0.31785925  0.27971452]
pvalue=array([ 0.42028131,  0.15951175,  0.00553257]))

laser on vs off:
[ -3.37954834  11.94496826   8.86297607]
[ 0.32117167  0.32698904  0.29496405]
[ -3.29710205  11.84603271   8.97540283]
[ 0.29989743  0.26315761  0.2807169 ]
pvalue=array([ 0.06340093,  0.02000121,  0.00656564]))

[ -3.32108643  11.93597412   8.85997803]
[ 0.30550212  0.2807169   0.32103171]
[ -3.21015869  11.80555908   8.90195068]
[ 0.3027981   0.30064577  0.31387543]
pvalue=array([ 0.01102817,  0.00185707,  0.35341694]))

display+laser on vs off

[ -3.3900415   11.97045166   8.94092529] mean 
[ 0.29199326  0.27401702  0.36492755] stdev
[ -3.35181641  11.79131836   9.08258301] mean
[ 0.28045763  0.27413692  0.28997096] stdev
Ttest_indResult(statistic=array([-0.93940919,  4.59839608, -3.02393647]), 
pvalue=array([  3.48665279e-01,   7.58246008e-06,   2.82549432e-03]))

test 2
[ -3.28960693  11.92098389   8.8839624 ]
[ 0.32375002  0.29151574  0.30637615]
[ -3.15544434  11.8512793    9.018125  ]
[ 0.3154189   0.30004444  0.29429766]
Ttest_indResult(statistic=array([-2.95332687,  1.65786786, -3.1422271 ]), 
pvalue=array([ 0.00352417,  0.0989276 ,  0.00193405]))

test 3
[ -3.39528809  12.01017578   8.88621094]
[ 0.32368148  0.33788268  0.29817381]
[ -3.34731934  11.8257959    9.05560059]
[ 0.30761407  0.28630563  0.32435417]
Ttest_indResult(statistic=array([-1.06885219,  4.14240827, -3.82540016]), 
pvalue=array([  2.86437622e-01,   5.08778230e-05,   1.74938818e-04]))

Conclusion:
The display does affect the reading, as does the laser although not 
to a great extent - and it does not affect the noise levels; difference is approx 0.5 degs max
Plan: need to do calibration sequence with laser on` (and measure with laser on)
but have laser off when doing this

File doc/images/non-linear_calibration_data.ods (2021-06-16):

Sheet: RBF
x | φ a=-1, p=1 | φ a=0, p=2 | φ a=1, p=-0.5 | ψ
 | -1 | 0 | 1
 | 1 | 2 | -0.5
-1.3 | 0.873715911688034 | 0.158523438529463 | -0.000178995985355 | 1.03206035423214
-1.28 | 0.889051602140828 | 0.171280482198524 | -0.000205359761955 | 1.0601267245774
-1.26 | 0.903571531977711 | 0.184842194718166 | -0.000235324021043 | 1.08817840267483
-1.24 | 0.917227266925415 | 0.199238472101442 | -0.000269336998325 | 1.11619640202853
-1.22 | 0.929972744735786 | 0.214498438697508 | -0.000307896404511 | 1.14416328702878
-1.2 | 0.941764533584249 | 0.230650242076125 | -0.000351554017803 | 1.17206322164257
-1.18 | 0.952562078335032 | 0.247720838155157 | -0.000400920589853 | 1.19988199590034
-1.16 | 0.96232793272161 | 0.265735767427682 | -0.000456671072266 | 1.22760702907703
-1.14 | 0.971027975583774 | 0.284718923287842 | -0.000519550168909 | 1.25522734870271
-1.12 | 0.978631609414885 | 0.304692313597763 | -0.000590378217073 | 1.28273354479558
-1.1 | 0.985111939603063 | 0.325675816780394 | -0.000670057398021 | 1.31011769898544
-1.08 | 0.990445932897216 | 0.347686933863189 | -0.000759578274586 | 1.33737328848582
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

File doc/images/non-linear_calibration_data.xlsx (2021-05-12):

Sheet: RBF
x | φ a=-1, p=1 | φ a=0, p=2 | φ a=1, p=-0.5 | ψ
 | -1 | 0 | 1
 | 1 | 2 | -0.5
-1.3 | 0.8737159117 | 0.1585234385 | -0.0001789959854 | 1.032060354
-1.28 | 0.8890516021 | 0.1712804822 | -0.000205359762 | 1.060126725
-1.26 | 0.903571532 | 0.1848421947 | -0.000235324021 | 1.088178403
-1.24 | 0.9172272669 | 0.1992384721 | -0.0002693369983 | 1.116196402
-1.22 | 0.9299727447 | 0.2144984387 | -0.0003078964045 | 1.144163287
-1.2 | 0.9417645336 | 0.2306502421 | -0.0003515540178 | 1.172063222
-1.18 | 0.9525620783 | 0.2477208382 | -0.0004009205899 | 1.199881996
-1.16 | 0.9623279327 | 0.2657357674 | -0.0004566710723 | 1.227607029
-1.14 | 0.9710279756 | 0.2847189233 | -0.0005195501689 | 1.255227349
-1.12 | 0.9786316094 | 0.3046923136 | -0.0005903782171 | 1.282733545
-1.1 | 0.9851119396 | 0.3256758168 | -0.000670057398 | 1.310117699
-1.08 | 0.9904459329 | 0.3476869339 | -0.0007595782746 | 1.337373288
-1.06 | 0.9946145538 | 0.370740538 | -0.0008600266502 | 1.364495065
-1.04 | 0.9976028777 | 0.3948486234 | -0.0009725907403 | 1.39147891
-1.02 | 0.99940018 | 0.4200200547 | -0.001098568643 | 1.418321666
-1 | 1 | 0.4462603203 | -0.001239376088 | 1.445020944
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

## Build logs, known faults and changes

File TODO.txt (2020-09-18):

Fix single click from measure screen - shake to access menu?
Update axis calibration routine
Check calibration routine
Check cal routine works on new hardware
Update manual to match hardware

Work on shetland attack pony website and migrate to webfaction
cancel server on mythic beasts

Try and order a bluenrg1 dev kit somehow?

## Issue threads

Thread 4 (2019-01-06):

Check power consumption levels when asleep and awake

furbrain, 2019-01-06:

furbrain, 2019-01-10:
Aha
The problem is with the PLL for the FRC - this pulls lots of mA when running... so just need to call OSCILLATOR_Initialise() after the sleep command.
For some reason VREGS = 1 draws about 0.150mA compared to 8.8uA with VREGS = 0 ... shuold be the other way round shurely???
Next I'm going to try <gulp> deep sleep...

furbrain, 2019-01-10:
need to enable voltage retention regulator, also set BOREN to only work when device running and not in sleep; and need a delay before entering deep sleep otherwise can brick it...
RETEN=1, VREGS=1 - >5uA
RETEN=1, VREGS=0 ->2.2uA - this is acceptabubble!

Closed 2019-01-13.

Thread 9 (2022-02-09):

Device Non Responsive for several minutes

PmSully, 2022-02-09:
At about 3 months it starts to refuse to turn on. After a minute of no response, try again and it'll turn on. Gets worse with age. It turns on about 20% of the time now without help. Plugging it in seems to wake it up. That works about 90% of the time, but seems to be losing effectiveness. Any idea for a fix? It's currently updated to the latest patch. Occasionally the display will freeze for 30 seconds during surveys and turn off.

imrcly, 2022-02-17:
After disconnecting the Bluetooth module the device turns on and off correctly. With the Bluetooth module connected the voltage drops from 3.85v to 3.75v when turned on when the device is not responding to turn on the power stays at 3.75v for 30seconds then the device power returns to 3.85v and the device will turn on again. This does not happen every time. It appears that the Bluetooth module is staying active and not powering off or going into the standby state.

Closed 2022-03-09.

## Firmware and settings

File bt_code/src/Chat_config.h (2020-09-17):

#ifndef _CHAT_CONFIG_H_
#define _CHAT_CONFIG_H_

#include "bluenrg1_stack.h"
#include "stack_user_cfg.h"

/* This file contains all the information needed to init the BlueNRG-1 stack.
 * These constants and variables are used from the BlueNRG-1 stack to reserve RAM and FLASH 
 * according the application requests
 */

/* Default number of link */
#define MIN_NUM_LINK                1
/* Default number of GAP and GATT services */
#define DEFAULT_NUM_GATT_SERVICES   2
/* Default number of GAP and GATT attributes */
#define DEFAULT_NUM_GATT_ATTRIBUTES 9

/* Enable/disable Data length extension Max supported ATT_MTU size based on OTA client & server Max ATT_MTU sizes capabilities */
#if (CONTROLLER_DATA_LENGTH_EXTENSION_ENABLED == 1) && (OTA_EXTENDED_PACKET_LEN == 1) 
  #define OTA_MAX_ATT_MTU_SIZE    (OTA_ATT_MTU_SIZE)   //(220)  /* OTA Client & Server supported ATT_MTU */   
#else /* BlueNRG-1 device: no data length extension support */
  #define OTA_MAX_ATT_MTU_SIZE    (DEFAULT_ATT_MTU)             /* DEFAULT_ATT_MTU size = 23 bytes */ 
#endif   

#if defined (ST_OTA_LOWER_APPLICATION) || defined (ST_OTA_HIGHER_APPLICATION)
/* Number of services requests from the chat demo */
#define NUM_APP_GATT_SERVICES (1 + 1) /* 1 Chat service + 1 OTA service */

/* Number of attributes requests from the chat demo */
#define NUM_APP_GATT_ATTRIBUTES (5 + 9) /* 5 attributes x BLE Chat service characteristics + 9 for OTA Service characteristics */

/**
 * Set the number of 16-bytes units used on an OTA FW data packet for matching OTA client MAX ATT_MTU
 */
#define OTA_16_BYTES_BLOCKS_NUMBER ((OTA_MAX_ATT_MTU_SIZE-4)/16)   /* 4 bytes for OTA sequence numbers + needs ack + checksum bytes */

/* OTA characteristics maximum lenght */
#define OTA_MAX_ATT_SIZE (4 + OTA_16_BYTES_BLOCKS_NUMBER * 16) 

#else /* NO OTA Service is required */
   
/* Number of services requests from the chat demo */
#define NUM_APP_GATT_SERVICES 1  /* 1 Chat service */

/* Number of attributes requests from the chat demo */
#define NUM_APP_GATT_ATTRIBUTES 5 /* 5 attributes x BLE Chat service characteristics */

/* OTA characteristics maximum lenght */
#define OTA_MAX_ATT_SIZE (0) 
   
#endif 

#define MAX_CHAR_LEN(a,b) ((a) > (b) )? (a) : (b)

/* Application characteristics maximum lenght */
#define _MAX_ATT_SIZE	(20) 

/* Set supported max value for attribute size: it is the biggest attribute size enabled by the application. */
#define APP_MAX_ATT_SIZE	  MAX_CHAR_LEN(OTA_MAX_ATT_SIZE,  _MAX_ATT_SIZE)

/* Number of links needed for the demo: 1
 * Only 1 the default
 */
#define NUM_LINKS               (MIN_NUM_LINK)

/* Number of GATT attributes needed for the chat demo. */
#define NUM_GATT_ATTRIBUTES     (DEFAULT_NUM_GATT_ATTRIBUTES + NUM_APP_GATT_ATTRIBUTES)

/* Number of GATT services needed for the chat demo. */
#define NUM_GATT_SERVICES       (DEFAULT_NUM_GATT_SERVICES + NUM_APP_GATT_SERVICES)


/* Array size for the attribute value for OTA service */
#if defined (ST_OTA_LOWER_APPLICATION) || defined (ST_OTA_HIGHER_APPLICATION)
/* OTA service: 4 characteristics (1 notify property): 99 bytes + 
   Image Content characteristic length = 4  + (OTA_16_BYTES_BLOCKS_NUMBER * 16); 4 for sequence number, checksum and needs acks bytes */
#define OTA_ATT_VALUE_ARRAY_SIZE (99 + (4 + (OTA_16_BYTES_BLOCKS_NUMBER * 16))) 
#else
#define OTA_ATT_VALUE_ARRAY_SIZE (0)       /* No OTA service is used */
#endif

/* Array size for the attribute value */
#if CLIENT
#define ATT_VALUE_ARRAY_SIZE    (44) //(GATT + GAP Services Characteristics)
#elif SERVER
#define ATT_VALUE_ARRAY_SIZE    (44 + 80 + OTA_ATT_VALUE_ARRAY_SIZE) //(GATT + GAP) = 44 + Chat  (TX (41) + RX (39) characteristics)   Services
#endif 

/* Flash security database size */
#define FLASH_SEC_DB_SIZE       (0x400)

/* Flash server database size */
#define FLASH_SERVER_DB_SIZE    (0x400)

/* Set supported max value for ATT_MTU enabled by the application */
#if (CONTROLLER_DATA_LENGTH_EXTENSION_ENABLED == 1) && (OTA_EXTENDED_PACKET_LEN == 1) 
  #define MAX_ATT_MTU             (OTA_MAX_ATT_MTU_SIZE)
#else
  #define MAX_ATT_MTU             (DEFAULT_ATT_MTU) 
#endif 

/* Set supported max value for attribute size: it is the biggest attribute size enabled by the application */
#define MAX_ATT_SIZE            (APP_MAX_ATT_SIZE)  

/* Set the minumum number of prepare write requests needed for a long write procedure for a characteristic with len > 20bytes: 
 * 
 * It returns 0 for characteristics with len <= 20bytes
 * 
 * NOTE: If prepare write requests are used for a characteristic (reliable write on multiple characteristics), then 
 * this value should be set to the number of prepare write needed by the application.
 * 
 *  [New parameter added on BLE stack v2.x] 
*/
#define PREPARE_WRITE_LIST_SIZE PREP_WRITE_X_ATT(MAX_ATT_SIZE) 

/* Additional number of memory blocks  to be added to the minimum */
#define OPT_MBLOCKS		(6) /* 6:  for reaching the max throughput: ~220kbps (same as BLE stack 1.x) */

/* Set the number of memory block for packet allocation */
#define MBLOCKS_COUNT           (MBLOCKS_CALC(PREPARE_WRITE_LIST_SIZE, MAX_ATT_MTU, NUM_LINKS) + OPT_MBLOCKS)

/* RAM reserved to manage all the data stack according the number of links,
 * number of services, number of attributes and attribute value length
 */
NO_INIT(uint32_t dyn_alloc_a[TOTAL_BUFFER_SIZE(NUM_LINKS,NUM_GATT_ATTRIBUTES,NUM_GATT_SERVICES,ATT_VALUE_ARRAY_SIZE,MBLOCKS_COUNT,CONTROLLER_DATA_LENGTH_EXTENSION_ENABLED)>>2]);

/* FLASH reserved to store all the security database information and
 * and the server database information
 */
NO_INIT_SECTION(uint32_t stacklib_flash_data[TOTAL_FLASH_BUFFER_SIZE(FLASH_SEC_DB_SIZE, FLASH_SERVER_DB_SIZE)>>2], ".noinit.stacklib_flash_data");

/* FLASH reserved to store: security root keys, static random address, public address */
NO_INIT_SECTION(uint8_t stacklib_stored_device_id_data[56], ".noinit.stacklib_stored_device_id_data");

/* Maximum duration of the connection event */
#define MAX_CONN_EVENT_LENGTH 0xFFFFFFFF

/* Sleep clock accuracy */
#if (LS_SOURCE == LS_SOURCE_INTERNAL_RO)

/* Sleep clock accuracy in Slave mode */
#define SLAVE_SLEEP_CLOCK_ACCURACY 500

/* Sleep clock accuracy in Master mode */
#define MASTER_SLEEP_CLOCK_ACCURACY MASTER_SCA_500ppm

#else

/* Sleep clock accuracy in Slave mode */
#define SLAVE_SLEEP_CLOCK_ACCURACY 100

/* Sleep clock accuracy in Master mode */
#define MASTER_SLEEP_CLOCK_ACCURACY MASTER_SCA_100ppm

#endif

/* Low Speed Oscillator source */
#if (LS_SOURCE == LS_SOURCE_INTERNAL_RO)
#define LOW_SPEED_SOURCE  1 // Internal RO
#else
#define LOW_SPEED_SOURCE  0 // External 32 KHz
#endif

/* High Speed start up time */
#define HS_STARTUP_TIME 328 // 800 us

/* Radio Config Hot Table */
extern uint8_t hot_table_radio_config[];

/* Low level hardware configuration data for the device */
#define CONFIG_TABLE            \
{                               \
  (uint32_t*)hot_table_radio_config,          \
  MAX_CONN_EVENT_LENGTH,        \
  SLAVE_SLEEP_CLOCK_ACCURACY,   \
  MASTER_SLEEP_CLOCK_ACCURACY,  \
  LOW_SPEED_SOURCE,             \
  HS_STARTUP_TIME               \
}

/* This structure contains memory and low level hardware configuration data for the device */
const BlueNRG_Stack_Initialization_t BlueNRG_Stack_Init_params = {
    (uint8_t*)stacklib_flash_data,
    FLASH_SEC_DB_SIZE,
    FLASH_SERVER_DB_SIZE,
    (uint8_t*)stacklib_stored_device_id_data,
    (uint8_t*)dyn_alloc_a,
    TOTAL_BUFFER_SIZE(NUM_LINKS,NUM_GATT_ATTRIBUTES,NUM_GATT_SERVICES,ATT_VALUE_ARRAY_SIZE,MBLOCKS_COUNT,CONTROLLER_DATA_LENGTH_EXTENSION_ENABLED),
    NUM_GATT_ATTRIBUTES,
    NUM_GATT_SERVICES,
    ATT_VALUE_ARRAY_SIZE,
    NUM_LINKS,
    0, /* reserved for future use */
    PREPARE_WRITE_LIST_SIZE,
    MBLOCKS_COUNT,
    MAX_ATT_MTU,
    CONFIG_TABLE,
};

#endif // _CHAT_CONFIG_H_

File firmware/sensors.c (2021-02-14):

#define USE_AND_OR
#include <string.h>
#include "config.h"
#include "sensors.h"
#include "display.h"
#include "i2c_util.h"
#include "maths.h"
#include "mcc_generated_files/rtcc.h"
#include "utils.h"
#include "exception.h"
#include <gsl/gsl_vector.h>
#include <gsl/gsl_matrix.h>
#include <gsl/gsl_sort_vector.h>
#include <gsl/gsl_statistics.h>
#include "gsl_static.h"
#include "version.h"
#include "laser.h"

GSL_MATRIX_DECLARE(temp_mag_readings, SAMPLES_PER_READING, 3);
GSL_MATRIX_DECLARE(temp_grav_readings, SAMPLES_PER_READING, 3);
GSL_MATRIX_DECLARE(temp_gyro_readings, SAMPLES_PER_READING, 3);

GSL_VECTOR_DECLARE(last_reading, 3);

#define length(a) sizeof(a)/sizeof(a[0])
#define send_multi(addr, commands) write_i2c_multi(addr, commands, length(commands))

#define MPU9250_ADDRESS 0x68
#define MPU9250_GYRO_FULL_SCALE 250
#define MPU9250_ACCEL_FULL_SCALE 2 
#define MPU9250_MAG_FULL_SCALE 4800

static const uint8_t ALPHA_AXES[] = {4, 0, 5, 0, 4, 5};
static const uint8_t V1_0_AXES[] = {4, 0, 5, 4, 3, 5};
static const uint8_t V1_1_AXES[] = {3, 4, 5, 4, 0, 2};


const uint8_t MPU9250_ACCEL_AXES[] = {4,0,5};
const uint8_t MPU9250_MAG_AXES[] = {0,4,5};
const uint8_t BM1422_MAG_AXES[] = {4,3,5};
const uint8_t LSM6DS3_ACCEL_AXES[] = {0,1,2};

#define BM1422_ADDRESS 0x0e
#define BM1422_ADDRESS_V11 0x0f
#define BM1422_MAG_FULL_SCALE 1376

#define LSM6DS3_ADDRESS 0x6b
#define LSM6DS3_ACCEL_FULL_SCALE 2 
#define LSM6DS3_GYRO_FULL_SCALE 286

float ACCEL_FULL_SCALE, MAG_FULL_SCALE, GYRO_FULL_SCALE;

const i2c_multi_commands MPU9250_init_commands[] = {
    {0x6A, 0},
    {0x6A,7},

    {0x19,9}, //gives sample rate of 100Hz
    {0x1A,0x42}, //FIFO Lockes, gyro 84Hz low-pass filter, no external sync
    {0x1B, 0}, //Gyro full scale 250 deg/s
    {0x1C, 0}, //Accel ful scale +/-2g
	{0x1D, 2}, //Accel 99Hz low-pass filter
    //set fifo enablement
	{0x37, 0x0}, //disable interrupt pin
	{0x38, 0}, //disable interrupt pin
    {0x23, 0x78}, //gyro+accel only
};

const i2c_multi_commands AK8963_commands[] = {

        //put i2c control stuff here
    {0x24, 0x40}, //I2C_MST_CTRL
    {0x25, 0x8C}, //SLV0_ADDR
    {0x26, 0x03}, //SLV0_REG
    {0x27, 0xD7}, //SLV0_CTRL
    {0x28, 0x0C}, //SLV1_ADDR
    {0x29, 0x0A}, //SLV1_REG
    {0x2A, 0x81}, //SLV1_CTRL
    {0x64, 0x11}, //SLV1_DO
    {0x34, 0x00}, //I2C_MST_DELAY
    {0x67, 0x83}, //I2C_MST_DELAY_CTRL  
    {0x23, 0x79}, //FIFO sensors - gyro, accel and i2c slave 0                    
};

const i2c_multi_commands MPU9250_reset_commands[] = {
    {0x6A, 0x67}, //USER_CTRL
    {0x6B, 0}, //PWR_MGMT_1    
};

const i2c_multi_commands BM1422_init_commands[] = {
    {0x1B, 0xC8}, //14bits, 100Hz read rate, continuous mode
    {0x5C, 0x00},
    {0x5D, 0x00}, //clear reset status
    {0x1C, 0x00}, //do not use Data ready pin
    {0x40, 0x10}, //average 16 readings together
    {0x1D, 0x40}, //set it going    
};

const i2c_multi_commands LSM6DS3_init_commands[] = {
    {0x1A, 0x0C}, //enable I2c pass-through and pull-ups
    {0x10, 0x43}, //accelerometer 104Hz output, 50Hz filter
    {0x11, 0x40}, //gyro 104Hz output, 250 dps fullscale
    {0x13, 0x80}, //enable filter for accelerometer
};

static
void set_axes(const uint8_t *axes) {
    memcpy(config.axes.accel, axes, 3);
    memcpy(config.axes.mag, &axes[3], 3);    
}


void sensors_init() {
    switch (version_hardware) {
        case VERSION_ALPHA:
            send_multi(MPU9250_ADDRESS, MPU9250_init_commands);
            send_multi(MPU9250_ADDRESS, AK8963_commands);
            send_multi(MPU9250_ADDRESS, MPU9250_reset_commands);
            ACCEL_FULL_SCALE = MPU9250_ACCEL_FULL_SCALE;
            GYRO_FULL_SCALE = MPU9250_GYRO_FULL_SCALE;
            MAG_FULL_SCALE = MPU9250_MAG_FULL_SCALE;
            if (config.axes.accel[0]>=5) {
                set_axes(ALPHA_AXES);
            }
            break;
        case VERSION_V1_0:
            send_multi(MPU9250_ADDRESS, MPU9250_init_commands);
            send_multi(MPU9250_ADDRESS, MPU9250_reset_commands);
            send_multi(BM1422_ADDRESS, BM1422_init_commands);
            ACCEL_FULL_SCALE = MPU9250_ACCEL_FULL_SCALE;
            GYRO_FULL_SCALE = MPU9250_GYRO_FULL_SCALE;
            MAG_FULL_SCALE = BM1422_MAG_FULL_SCALE;
            if (config.axes.accel[0]>=5) {
                set_axes(V1_0_AXES);
            }
            break;
        case VERSION_V1_1:
            send_multi(LSM6DS3_ADDRESS, LSM6DS3_init_commands);
            send_multi(BM1422_ADDRESS_V11, BM1422_init_commands);
            ACCEL_FULL_SCALE = LSM6DS3_ACCEL_FULL_SCALE;
            GYRO_FULL_SCALE = LSM6DS3_GYRO_FULL_SCALE;
            MAG_FULL_SCALE = BM1422_MAG_FULL_SCALE;
            if (config.axes.accel[0]>=5) {
                set_axes(V1_1_AXES);
            }
            break;
        default:
            break;          
    }
}



void byte_swap(uint16_t *word){
    *word = (*word << 8 | *word >> 8);    
}

void sensors_read_raw(struct RAW_SENSORS *sensors){
    int i;
    switch (version_hardware) {
        case VERSION_ALPHA:
            if (read_i2c_data(MPU9250_ADDRESS, 0x3B, (uint8_t *)sensors, sizeof(*sensors))) {
                THROW_WITH_REASON("I2C communication failed", ERROR_MAGNETOMETER_FAILED);
            }
            for(i=0; i< 10; ++i) {
                byte_swap(&((uint16_t*)sensors)[i]);
            }
            break;
        case VERSION_V1_0:
            if (read_i2c_data(MPU9250_ADDRESS, 0x3B, (uint8_t *)sensors, 14)) {
                THROW_WITH_REASON("MPU9250 communication failed", ERROR_MAGNETOMETER_FAILED);
            }
            for(i=0; i< 7; ++i) {
                byte_swap(&((uint16_t*)sensors)[i]);
            }
            if (read_i2c_data(BM1422_ADDRESS, 0x10, (uint8_t *)sensors->mag, 6)) {
                THROW_WITH_REASON("BM1422 communication failed", ERROR_MAGNETOMETER_FAILED);
            }
            break;
        case VERSION_V1_1:
            if (read_i2c_data(LSM6DS3_ADDRESS, 0x28, (uint8_t *)sensors, 6)) {
                THROW_WITH_REASON("LSM6DS3 communication failed", ERROR_MAGNETOMETER_FAILED);
            }
            if (read_i2c_data(LSM6DS3_ADDRESS, 0x20, (uint8_t *)&sensors->temp, 2)) {
                THROW_WITH_REASON("LSM6DS3 communication failed", ERROR_MAGNETOMETER_FAILED);
            }
            if (read_i2c_data(LSM6DS3_ADDRESS, 0x22, (uint8_t *)sensors->gyro, 6)) {
                THROW_WITH_REASON("LSM6DS3 communication failed", ERROR_MAGNETOMETER_FAILED);
            }
            if (read_i2c_data(BM1422_ADDRESS_V11, 0x10, (uint8_t *)sensors->mag, 6)) {
                THROW_WITH_REASON("BM1422 communication failed", ERROR_MAGNETOMETER_FAILED);
            }
            break;            
        default:
            THROW_WITH_REASON("Bad Hardware", ERROR_HARDWARE_NOT_IDENTIFIED);
            break;
    }
}
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

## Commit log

2018-06-10 Add chip descriptions etc
    [template.ods]
2018-06-10 Add 3d drawings
    [box.fcstd, boxl.fcstd, button.fcstd]
2018-06-10 Do PCB designs
    [cpu.sch, display.sch, power.sch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]
2018-06-10 Change to using modular display
    [display.sch]
2018-06-10 Start moving things into place on PCB
2018-06-11 Fix net bugs
    [display.sch, sensors.sch]
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2018-06-11 Finalise PCB design (for now)
2018-06-13 Create gerbers and gcode for home milling
    [SAP.bottom.gbr, SAP.bottommask.gbr, SAP.fab.gbr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]
2018-06-22 Update power chain to use nicer chips for home use
    [power.sch]
2018-06-22 Use separate sensor board
    [sensors.sch]
2018-06-22 Fix footprints
    [power.sch]
2018-06-22 Change to 0603 passive components
    [cpu.sch]
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2018-07-01 Install delay_ms function and use it Remove speed argument from all I2C functions All chips use fast I2C
2018-07-02 Update to correctly use I2C (needs interrupts enabled) Various other fixes Hello world is working!
    [main.c]
2018-07-03 Import sensors and config.h
2018-07-03 Make working on accel display Problem is very slow update - seems to be an oscillator problem
    [main.c]
2018-07-10 Update schematic - correct errors and add status leds
    [display.sch, power.sch]
2018-07-16 Get USB and UART working
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2018-07-24 Import new footprints
    [power.sch, usb.sch]
2018-07-24 Add ADC holding cap
    [cpu.sch]
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2018-07-24 Add code for spider
    [frame.scad, frame.stl]
2018-07-26 Various pcb fixes
    [power.sch]
2018-08-01 update gitignore
    [SAP.bottom.gbr, SAP.bottommask.gbr, SAP.fab.gbr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]
2018-08-01 Update spider frame and PCB
    [frame.scad, frame.stl]
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2018-08-09 Fix bug jumping to app
    [main.c]
2018-08-17 Move cutout on frame
    [frame.scad, frame.stl]
2018-08-17 Try and get UART working with USB (failed)
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2018-08-21 Add stub calibration code, including code to determine axis orientation
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2018-09-14 Start work on leg storage interface and module
2018-10-02 Start working on fixes for leg storage funcs
2018-10-03 Include testcase where lsb of leg->dt lsb is 0xff
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2018-11-15 Add Square root function, and switch find plane to use gsl
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2018-12-03 Rejig calibration routine, and tidy laser on_off functions
2018-12-06 Get calibration routine running Add global exception handler (but it isn't working - maybe no linked right?)
2018-12-10 Convert accum to double, and switch least squares solver
2018-12-10 Move some of the leg management code into its own file, and update tests... Add ceedling suite for running on an actual chip to avoid simulator burps
2018-12-11 move stuff from storage to config and leg
2018-12-11 Fix bug in leg / config code in simulator
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2018-12-23 Bug fixes - enables compilation and running on real pony
    [main.c]
2018-12-23 Convert USB display routine to work as an APP... This recreates pretty much all the code that gets run when USB is connected Only real difference is no power supply...
2018-12-28 Fix erroneous capacitor value
    [cpu.sch]
2018-12-28 Make main loop reset instead of loop
    [main.c]
2018-12-29 Change struct SURVEY.forward to last_leg_forward, and add survey_add_leg
    This tells us if the last leg in the current survey was forward or backwards
    Update the stuff in leg.c to give us this info when scanning a leg
2018-12-30 Add tests for laser.[ch] and raise exceptions if errors
    Also change test harness slightly to only alter function calls/declarations
    if TEST is true, not __DEBUG (which could cause errors while debugging...)
2018-12-30 Try to get battery voltage detection working - still reasing 0...
2019-01-02 Finish work on model code - just need to manage splay legs - maybe by just stopping find_station from finding them and thus they will always be treated as unknown stations
2019-01-02 Add correction for splay legs
2019-01-03 Various fixes to get tests all working again
    test:laser is shonky on simulator - I suspect due to the
    usual bug
    Also reset battery_get_voltage to theoretically correct set-up
2019-01-16 Add capacitor to goltage divider, correct capacitance of Vcap Add pullup resistors to I2C lines
    [cpu.sch, sensors.sch]
2019-01-16 Update schematics for final circuitry
    [cpu.sch, power.sch, sensors.sch]
2019-01-16 Update footprints and model numbers for everything to ease Seeed order
    [cpu.sch, display.sch, power.sch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]
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2019-01-16 Final PCB fettlings
    [cpu.sch, power.sch]
2019-01-17 Correct errors in BOM
    [cpu.sch, display.sch, sensors.sch]
2019-01-17 Fix oled footprint to show exclusion zones
2019-01-17 At slightly nicer pcb footprint for qfn and oled
    [sensors.sch]
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2019-01-19 Various updates to hardware, getting ready for upload to seeed
    [cpu.sch, power.sch]
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2019-01-19 Added new USB outline, finalised zip-file and excel file
    [SAP.xls, usb.sch]
2019-01-24 Start work on functions to read configs and legs simply
2019-01-26 Add pcb gerber files
    [SAP.DRL, SAP.GBL, SAP.GBO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]
2019-02-10 switch to using wxwidgets document/view model Add new, save as, save code
2019-03-17 Stuff for drilling the end panel
    [end_panel_jig.fcstd]
2019-03-17 Fix errors in ADC code
    [beep.c, main.c]
2019-03-17 Throw error message if comms difficulties with MPU9250
    [sensors.c]
2019-04-08 Some hardware additions
    [button_hole.dxf, button_hole.fcstd, end_panel.fcstd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]
2019-04-15 Add footprint and symbol for new timer chip
2019-04-15 PCB changes - remove charging LED, replace Sit1630 with a bigger part, adapt ICSP header for use with bluetooth module
    [cpu.sch, power.sch]
2019-04-17 Add bits for bluetooth adapter circuit
    [adapter.sch]
2019-04-18 change display_on(bool) and laser_on(bool) to x_on() and x_off()
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2019-04-18 Fix errors in button detection code
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2019-05-05 Add UART2 support - deliberately not included in system init code
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2019-06-04 Fix bug in bootloader - occasionally stops recognising button presses
    Seems to have been fixed by Oscillator init code - possibly something to
    do with RNMICON???
    [main.c]
2019-06-04 Various bug fixes, make shutdown nicer
    [display.c, main.c]
2019-06-12 Remove all references to vectorr or matrixx, replace matrixx with calibration struct
    [sensors.c]
2019-06-23 Fix bug that stops clock speed changes
    [main.c]
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2019-06-29 Re-do isntructions for calibration and various tidyings up
2019-07-26 Fix incorrect footprint for display
    [display.sch]
2019-07-26 Make usb connector central. Couple of minor bug fixes
2019-11-15 Fix hardware bloopers
    [base.stl, button_hole.fcstd, cage.stl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]
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2019-11-15 Remove output files
    [SAP.DRL, SAP.GBL, SAP.GBO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]
2019-11-15 Add battery data
    [battery.csv, battery2.csv]
2019-11-15 Board fixes
    [SAP.xls]
2019-11-15 Add info on which pins are which on laser module
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2020-01-12 Make 3d printed end panel and jig for holding wires to solder laser
    [end_panel2.FCStd, end_panel2.stl, laser_jig.FCStd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]
2020-01-15 Fix timeout on laser
2020-01-15 Update to use new sensors
    [sensors.sch]
2020-01-29 Finalise V1 PCB
    [SAP.csv, SAP.xls, cpu.sch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]
2020-02-06 Remove software folder
    [battery.csv, battery2.csv]
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2020-02-09 Fix bug with changing your sensor suite, add checksum to version info
    [sensors.c]
2020-02-09 Improve calibration process, now requires two shots at different point after each other
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2020-04-13 refactor leg code and bug fixes
2020-04-29 Fix spaces and add yes/no UI
    [display.c]
2020-05-02 Convert display to use avoid explicit use of buffer and encapsulate everything
    [display.c, main.c]
2020-09-17 add slot for bt module and fix button hole design
    [ble_mount_jig.FCStd, ble_mount_jig.stl, button_hole.dxf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]
2020-09-17 Refactor to give separate mag and accel axes on calibration
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2021-01-16 Various bug fixes
    [base.stl, cage.stl, end_panel2.FCStd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]
2021-01-16 various updates
    [end_panel2.dxf, model.FCStd]
2021-01-16 UPdate pcb
    [SAP.csv]
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2021-01-16 Switch to using minimizer to align sensors with laser
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2021-04-07 Add orientation marker to U8
    Update BOM
    [SAP.xls]
2021-04-17 work on article
    [non-linearity.csv]
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2021-06-16 Add magazine article details
    [non-linear_calibration_data.ods]
2021-07-04 Fix minor issue with usb socket retainer
    [frame.FCStd, frame.stl]
2022-03-09 Fix #9
    Actually two bugs: one is peripherals getting turned on and off again
    quickly - this can cause the laser module to draw too much power and shut
    down the regulator. In combination with BT module, this turns off the error
    beep as it is powered via the BT module. Display also does not work. This is
    fixed with a simple firmware update, which will be released imminently.
    Second bug appears to be in the bootloader code. Port C9 is the button, and
    currently only responds to a falling edge during sleep. If the button is pressed
    on entry to sleep, the processor believes it is permanently held down,
    and will not respond to falling edges. Fix is to make sensitive to changes in
    either direction.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
    [main.c]
2022-05-18 New body design
    [acrylic.dxf, gaskets.dxf, model-Body.stl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]
2022-06-26 further work on new case
    [model-Body.stl, model-LCD Holder.stl, model.FCStd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]
2022-06-26 Add code to read case length from bootloader
